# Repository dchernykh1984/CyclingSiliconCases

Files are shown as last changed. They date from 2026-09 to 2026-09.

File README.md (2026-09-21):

# CyclingSiliconCases

Чехлы для велокомпьютеров Garmin. Исходные модели скачаны готовыми, лежат
в [input_data/](input_data/) и правятся кодом поверх них. Готовые STL
собирает CI и прикладывает к релизу — в репозитории их нет.

Python 3.11–3.13, uv, numpy, manifold3d, fontTools. Внешних программ
ставить не нужно: булевы операции считает manifold3d (тот же движок, что
внутри современного OpenSCAD, только как библиотека), картинки рисует свой
растеризатор, шрифт надписи лежит в репозитории.

## Быстрый старт

```bash
make install          # зависимости (uv) и хуки pre-commit
make test             # pytest
make build            # STL в ./dist
make preview          # PNG в ./preview
make inspect          # из каких тел состоят исходники
```

## Что в релизе

| Файл | Прибор | Что сделано |
| --- | --- | --- |
| `garmin-830.stl` | Edge 830 | выпуклая надпись **UBT 8 YEARS** на передней стенке, губы удержания по бокам и спереди |
| `garmin-840.stl` | Edge 840 | только чехол из раскладки, окна под все кнопки, выпуклая надпись **UBT 8 YEARS** на носу |
| `can-lid.stl` | банка для инструмента ⌀77 | выпуклая надпись **UBT 8 YEARS** на наружном торце |
| `bottle-cap.stl` | фляжка для инструмента ⌀72 | выпуклая надпись **UBT 8 YEARS** на наружном торце |
| `can.stl` | — | сама банка, без правок: копия исходника байт в байт |
| `bottle.stl` | — | сама фляжка, без правок формы: повёрнута на дно |

Релиз отдаёт набор целиком: скачали всё, отправили в слайсер, напечатали.
**Все шесть файлов уже лежат так, как их надо печатать** — разворачивать
ничего не нужно.

Банку и фляжку мы не правим. Банка уходит побайтовой копией исходника;
фляжка в исходнике лежала на боку, и её пришлось поставить на дно — это
поворот, а не правка формы: число треугольников и объём до и после
совпадают, и это проверено тестом.

Ориентация у обоих чехлов одна: Z — от спинки к экрану, **+Y — вперёд по
ходу движения** (передняя стенка, там надпись), −Y — к велосипедисту (там
кнопки нижнего торца), −X — левый бок прибора, если смотреть на экран.

### Надпись

Надпись **выпуклая**, высотой 0.8 мм. Под TPU это единственный разумный
вариант: гравировку глубиной в полмиллиметра слайсер на наружной стенке
затирает периметром, а наружу буква растёт свободно. Шрифт — Roboto Black;
при высоте прописной 4 мм стойка буквы выходит 0.92 мм, то есть два
периметра сопла 0.4 мм.

Ни одна стенка чехла не плоская, поэтому надпись кладётся **по поверхности**:
стенка сначала измеряется лучами, потом плитка с буквами гнётся по замеру.
Высота рельефа получается одинаковой по всей строке — 0.78…0.81 мм на 830 и
0.75…0.80 мм на 840, где нос представляет собой скруглённый гребень. Плоская
плитка на том же месте в середине торчала бы на 0.8 мм, а по краям тонула на
два-три миллиметра.

### Кнопки

У Edge 830 три кнопки: питание на левом боку, lap и start/stop на нижнем
торце. Исходный чехол открывает все три — окно 15 × 9 мм слева и окно
44 × 10 мм по всему заднему торцу. Резать нечего, геометрия окон не тронута.

У Edge 840 кнопок семь: питание, вверх и вниз слева, выбор и назад справа,
lap и start/stop на нижнем торце. Точных координат нет ни в мануале, ни в
обзорах — но их знал автор исходника: в полости чехла размечены карманы, где
стенка утончена с 1.75 до 0.75 мм. Слева таких карманов два (50.5…78.0 мм
под пару «вверх/вниз» и 83.5…98.0 мм под питание), справа тоже два
(50.5…65.0 и 83.5…98.0) — три кнопки слева и две справа, ровно как у
прибора. Окна прорезаны **по этим карманам**, так что между ними остаются
рёбра исходника в полную толщину: 6.5 мм до первого окна, 5.5 мм между
окнами слева, 18.5 мм справа и 9 мм до носа.

Кнопки нижнего торца (lap и start/stop) автор не разметил — там была
сплошная стенка 4.5 мм. Их нашли по модели самого прибора: они стоят не
по центру торца, а на завалах углов, в 18.7 мм от середины в обе стороны.
Под них прорезаны **два окна по 7 мм**, между ними остаётся 30 мм торца.

Мембрана 0.75 мм в TPU продавливается пальцем, но полагаться на неё не
стоит: именно тонкая стенка рвётся первой, и цепляются как раз за неё.

### Сверка с прибором

В `input_data` лежит модель самого Edge 840. По ней проверяется то, что
раньше приходилось предполагать:

```bash
uv run cycling-cases fit garmin-840
```

Прибор садится в полость без натяга (зазор по бокам 0.16…0.37 мм),
задняя грань ложится на дно рамки, а вверх его не вынуть: рамка над ним
сужается до 53.4 мм при ширине прибора 58.2 — заводят его снизу, со
стороны крепления. Все семь кнопок попадают в окна с запасом не меньше
0.35 мм по кромке.

Модель приехала под именем «garmin edge 830 Mesh.stl», но по размерам
это Edge 840 — подробности в [input_data/README.md](input_data/README.md).

### Крышки банки и фляжки

Наружный торец у обеих крышек — плоский диск, поэтому надпись ложится
на него без всякого изгиба, и рельеф выходит ровно 0.8 мм по всей
строке. Высота прописной 7 мм, строка 60.7 мм, стойка буквы 1.61 мм.

**Печатать крышку надо надписью вверх, то есть открытой стороной вниз,
и под потолок над резьбой нужна поддержка.** Иначе никак: выпуклые
буквы на грани, которая лежит на столе, пришлось бы печатать в
воздухе. В файле крышка уже стоит так, как её нужно печатать.

Если поддержку ставить не хочется — скажите, и надпись станет
гравировкой: крышка тогда печатается торцом вниз и без поддержек, но
буквы будут вдавленными.

### Посадка

Чехол 830 держался в основном креплением Garmin: загиб, удерживающий прибор
за лицевую рамку, был только на заднем торце. Добавлены такие же губы по
двум бокам и спереди — валик с наклонной нижней гранью (34–45°, печатается
без поддержек), заходящий на рамку на 0.8 мм. По ширине полость 50.6 мм при
приборе 50 мм, так что две губы оставляют натяг 1.0 мм. Над кромкой чехла
губы не поднимаются — это проверено тестом.

Чехол 840 — бампер-рамка: она открыта и сверху, и снизу. Так задумано в
исходнике, и иначе нельзя: снизу к прибору подходит крепление Garmin, сверху
остаётся экран. Держит прибор верхняя губа рамки, она прорезку окон пережила.

## Что где лежит

| Путь | Что там |
| --- | --- |
| `input_data/` | исходные модели, скачанные готовыми; их не пересобрать, это исходный код |
| `src/cycling_cases/recipes.py` | все правки и все числа с объяснением, откуда они взялись |
| `src/cycling_cases/cases.py` | каталог: какой исходник каким рецептом правится |
| `src/cycling_cases/mesh.py` | измерительный инструмент: тела, лучи, сечения, отступы |
| `src/cycling_cases/panel.py` | замер стенки и надпись по измеренной поверхности |
| `src/cycling_cases/lettering.py` | буквы из TTF в плоские контуры |
| `src/cycling_cases/solid.py` | мост к manifold3d и примитивы правок |
| `src/cycling_cases/preview.py` | растеризатор для картинок |
| `tests/` | приёмка исходников и замеры по готовым деталям |

```bash
uv run cycling-cases list                    # что за чехлы и что с ними
uv run cycling-cases inspect Garmin840.stl   # тела, размеры, замкнутость
uv run cycling-cases split Garmin840.stl     # разложить раскладку по телам
uv run cycling-cases build --out dist        # собрать всё
uv run cycling-cases preview --out preview   # отрендерить, чтобы посмотреть
```

## Как добавить ещё один чехол

Чехлы между собой не связаны: общие у них только утилиты — чтение сетки,
замеры, булевы операции и надписи. Добавление нового — четыре шага:

1. положить скачанный STL в `input_data/` и записать в
   [input_data/README.md](input_data/README.md), откуда модель и на каких
   условиях;
2. посмотреть, что в нём: `uv run cycling-cases inspect <файл>`;
3. написать рецепт в `recipes.py` — функция берёт сетку и возвращает тело;
4. дописать одну запись в `CASES` (`src/cycling_cases/cases.py`).

Тест `test_every_source_is_registered` не даст забыть четвёртый шаг.

## Правила, которые не обсуждаются

- **В репозитории только код и исходники.** Собранные STL и превью не
  коммитятся: их делает CI и кладёт в релиз.
- **Геометрия проверяется расчётом, а не на глаз.** Всё, что должно
  поместиться на деталь, считается в `tests/` по готовой детали. Рендер —
  вторая проверка, а не первая.
- **Коммит — одна строка** в стиле conventional commits: от типа зависит
  версия, которую поставит release-please.
- **Чужие формы не переделываем молча.** Откуда взялась модель и на каких
  условиях — в [input_data/README.md](input_data/README.md); что именно мы
  с ней делаем и из каких чисел это следует — в `recipes.py`.

Подробности для тех, кто правит модели, — в `.claude/skills/`.

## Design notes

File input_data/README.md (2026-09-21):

# Исходные модели

Эти файлы нарисовали не мы — они скачаны готовыми. Пересобрать их не из чего,
поэтому они лежат в git наравне с кодом: это исходники, а не артефакты сборки.

| Файл | Что это | Откуда | Лицензия |
| --- | --- | --- | --- |
| `Garmin830.stl` | чехол Garmin Edge 830, одна деталь | **не записано** | **не записано** |
| `Garmin840.stl` | раскладка на стол для Garmin Edge 840: вынос, чехол, два хомута, две проставки | **не записано** | **не записано** |
| `Garmin840Device.stl` | сам велокомпьютер Garmin Edge 840 — шаблон для сверки | прислан заказчиком | **не записано** |
| `obj_1_Lid.stl` | крышка банки для инструмента, ⌀77 мм | прислан заказчиком | **не записано** |
| `obj_2_Can 170mm.stl` | банка для инструмента, ⌀77 × 170 мм | прислан заказчиком | **не записано** |
| `水壶盖3.1无孔.STL` | крышка фляжки для инструмента, ⌀72 мм | прислан заказчиком | **не записано** |
| `水壶3.3.STL` | фляжка для инструмента, ⌀72 × 166 мм | прислан заказчиком | **не записано** |

> **Про банку и фляжку решено: выкладываем как есть.** Владелец
> репозитория не помнит, откуда скачаны эти четыре файла, восстановить
> источник не получилось, и решение — не искать дальше, а публиковать.
> Так что графа «лицензия» у них останется пустой сознательно, а не по
> забывчивости. Риск понятен и принят; если правообладатель однажды
> найдётся, файлы придётся убрать из релизов, а формы нарисовать свои.
>
> На новые модели правило ниже по-прежнему распространяется.

## Почему это важно заполнить

Опыт соседнего проекта: часть моделей на Printables и Thingiverse выложена
под **CC BY-NC** или **CC BY-NC-SA** — некоммерческая лицензия, иногда ещё
и с требованием распространять производное на тех же условиях. Такую модель
нельзя ни положить в публичный репозиторий как основу продукта, ни приложить
к релизу, ни нанести на неё логотип спонсора. Выяснять это лучше до того,
как вокруг чужой формы вырос проект.

Что нужно записать по каждой модели:

- ссылку на страницу, откуда скачано;
- имя автора;
- лицензию дословно (CC0 / CC BY / CC BY-SA / CC BY-NC / CC BY-NC-SA / иное).

Если модель окажется под некоммерческой лицензией, а сделать с ней нужно
что-то, чего лицензия не разрешает, — форму рисуем свою по размерам
велокомпьютера. Размеры — это факты, они не охраняются; охраняется чужое
творческое решение.

## Банка и фляжка под инструмент

Две пары «сосуд + крышка» в форме велосипедной фляжки. Имена файлов
оставлены такими, какими приехали, — в том числе иероглифические и с
пробелом; откуда какой файл, видно по таблице выше.

| Файл | Тел | Габарит, мм | Замкнут |
| --- | --- | --- | --- |
| `obj_1_Lid.stl` | 1 | 76.99 × 76.98 × 16.60 | да |
| `obj_2_Can 170mm.stl` | 1 | 77.00 × 76.99 × 170.00 | да |
| `水壶盖3.1无孔.STL` | 1 | 72.00 × 15.00 × 72.00 | да |
| `水壶3.3.STL` | 1 | 72.00 × 166.17 × 72.00 | да |

У обеих крышек наружный торец — плоский диск, изнутри резьба. Дно
крышки банки 1.60 мм, крышки фляжки 1.75 мм. Крышка фляжки лежит в
файле на боку: её ось идёт вдоль Y, а не Z.

Расширение у иероглифических файлов записано прописными (`.STL`).
Шаблон `*.stl` на Linux их не находит, поэтому в коде расширение
сверяется без учёта регистра.

Правим мы только крышки — на них ложится надпись. Банка и фляжка идут
в релиз без правок формы: смысл релиза в том, чтобы скачать его целиком
и пойти печатать.

Банка уходит **копией байт в байт**, без пересохранения: прогон чужой
сетки через наш экспорт сшил бы вершины и переписал координаты во
float32 — получился бы немного другой файл, выданный за тот же самый.

Фляжка в исходнике лежит на боку (ось вдоль Y), и её мы **ставим на
дно**. Поворот идёт прямо по треугольникам, мимо булева движка: их число
и объём детали до и после совпадают. Дном вниз, а не горлышком — это
тоже проверяется тестом, потому что обратный поворот дал бы и ту же
высоту, и тот же объём.

## Что внутри файлов

Полная опись тел — в скилле `input-models`. Коротко:

- **`Garmin830.stl`** — готовый чехол одним замкнутым телом, 53.6 × 86.6 × 20.1 мм.
  Режется булевыми операциями без предварительной починки.
- **`Garmin840.stl`** — шесть тел на площадке 300 × 169 мм. Сам чехол —
  второе по величине тело, 60.0 × 103.6 × 17.0 мм; у него четыре ребра
  принадлежат четырём граням (деталь сама себя касается), дырок нет.

### Garmin840Device.stl — шаблон самого прибора

Модель прибора, а не чехла: по ней видно, попадают ли окна в кнопки и
лезет ли прибор в полость. Без неё чехол правится вслепую.

**Файл приехал под именем `garmin edge 830 Mesh.stl`, но это не 830.**
Габарит модели 58.29 × 85.53 × 19.66 мм; у Edge 830 — 50 × 82 × 20, у
Edge 840 — 57.8 × 85.1 × 19.6. По ширине разница с 830 почти восемь
миллиметров, в полость чехла 830 (50.6 мм) такой прибор не войдёт. Зато
в полость чехла 840 он садится с зазором 0.2 мм по ширине. Кнопок на
модели семь: три на левом боку, две на правом, две на нижнем торце —
столько их у 840; у 830 их три.

Два обстоятельства, которые надо знать, прежде чем брать этот файл:

* **единицы — десятые доли миллиметра.** В файле габарит 855 × 197 × 583.
  Множитель `0.1` записан в `devices.Device.units`;
* **в репозитории лежит прореженная копия.** Оригинал весит 16 МБ
  (326 456 треугольников) — столько в git класть незачем. В репозиторий
  ушла копия с допуском 0.05 мм: 17 874 треугольника, 0.9 МБ, габарит
  отличается на 0.025 мм. Замеры кнопок по ней совпадают с замерами по
  оригиналу до сотых.

Оригиналы сырых сканов кладите в `input_data` под именем с `Mesh` —
git такие файлы игнорирует. Прореженная копия делается так:

```python
from cycling_cases import solid
from cycling_cases.mesh import parts, read_stl, write_stl
body = parts(read_stl(Path("input_data/имя Mesh.stl")))[0].triangles
write_stl(Path("input_data/Имя.stl"), solid.to_triangles(solid.from_triangles(body).simplify(0.5)))
```

(`simplify` меряет допуск в единицах файла, поэтому 0.5 — это 0.05 мм.)

### Разметка кнопок в чехле 840

Автор исходника знал, где у Edge 840 боковые кнопки, и оставил под ними
карманы: стенка там утончена с 1.75 до 0.75 мм. Сквозное окно он прорезал
только одно на бок — 9 × 9 мм в 4…13 мм от заднего торца.

| Бок | Карманы по длине (Y исходника) | Длина |
| --- | --- | --- |
| левый | 50.5…78.0 и 83.5…98.0 | 27.5 и 14.5 мм |
| правый | 50.5…65.0 и 83.5…98.0 | 14.5 и 14.5 мм |

Три зоны слева и две справа — ровно столько боковых кнопок у Edge 840
(питание, вверх, вниз слева; выбор и назад справа). Карманы кончаются сверху
на той же высоте 6.7 мм, что и штатное окно, — это и есть пояс кнопок.

Наши окна режутся ровно по этой разметке, поэтому она проверяется приёмкой
(`test_the_840_case_has_its_buttons_marked_from_the_inside`): если исходник
заменят, а карманы окажутся в других местах, тест скажет об этом до того, как
окна уедут мимо кнопок.

Модель прибора эту разметку подтвердила: все пять боковых кнопок садятся в
свои карманы, причём верхняя кромка каждой кнопки совпадает с кромкой
кармана с точностью 0.01 мм. А вот кнопки нижнего торца автор не разметил
никак — их пришлось искать по модели прибора, и они оказались не по центру
торца, а на завалах углов, в 18.7 мм от середины.

Посмотреть самому:

```bash
uv run cycling-cases inspect Garmin840.stl
uv run cycling-cases split Garmin840.stl --out dist/parts
```

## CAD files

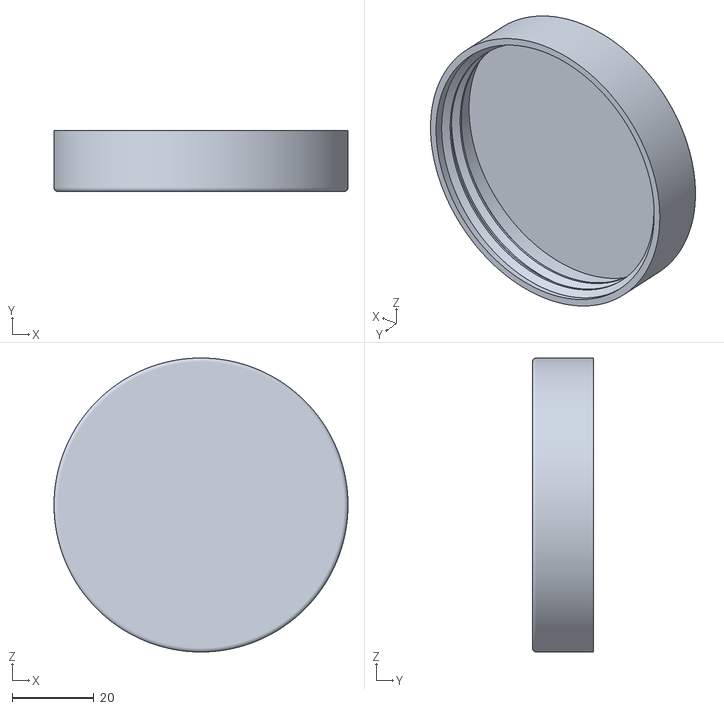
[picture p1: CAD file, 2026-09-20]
input_data/水壶盖3.1无孔.STL
72.0 x 15.0 x 72.0

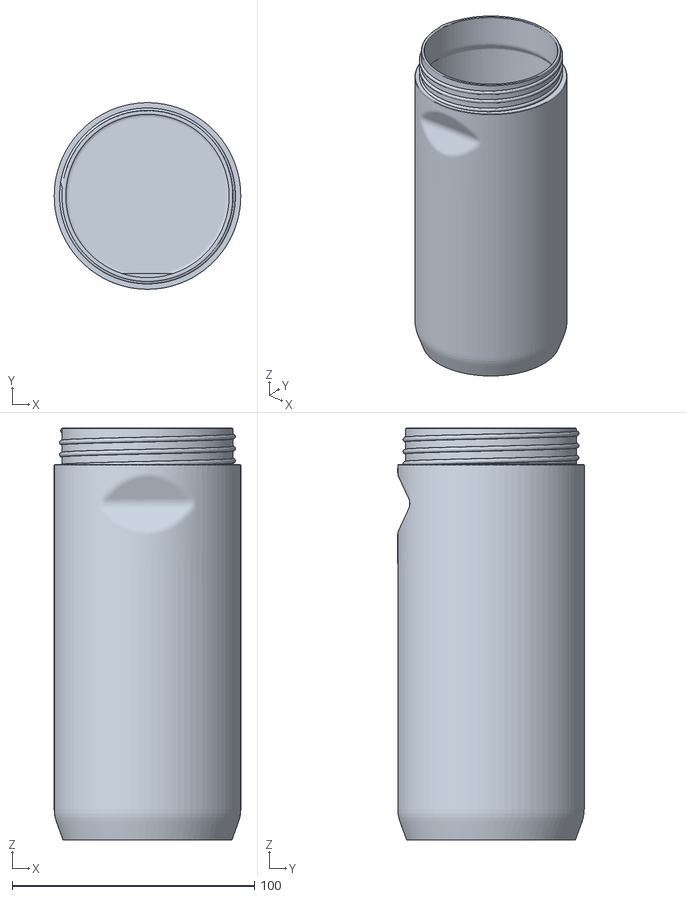
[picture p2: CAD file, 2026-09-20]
input_data/obj_2_Can 170mm.stl
77.0 x 77.0 x 170.0

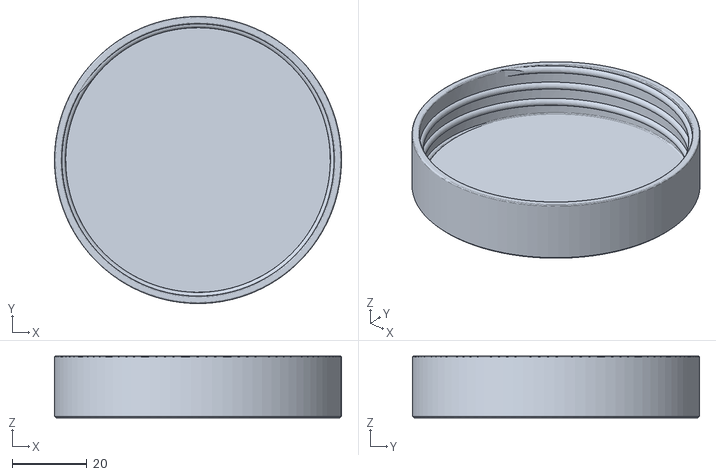
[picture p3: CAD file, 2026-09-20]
input_data/obj_1_Lid.stl
77.0 x 77.0 x 16.6

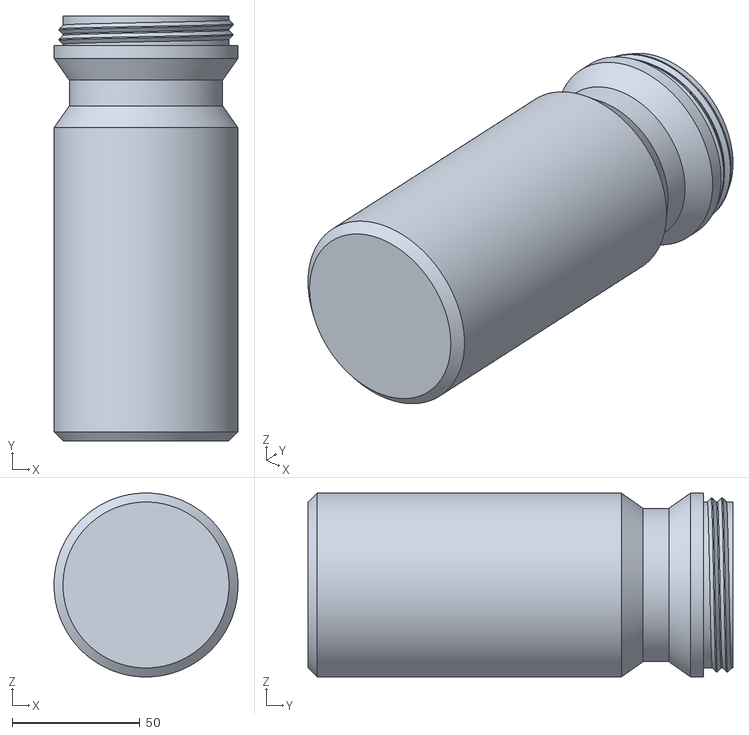
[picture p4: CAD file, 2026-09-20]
input_data/水壶3.3.STL
72.0 x 166.2 x 72.0

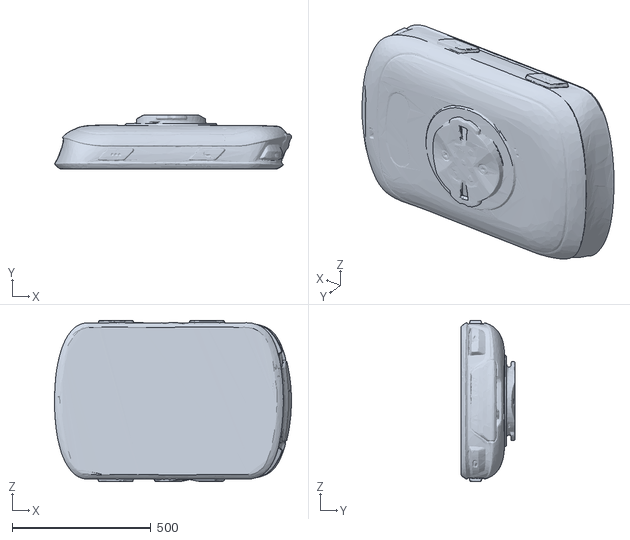
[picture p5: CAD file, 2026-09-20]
input_data/Garmin840Device.stl
855.3 x 196.6 x 582.7

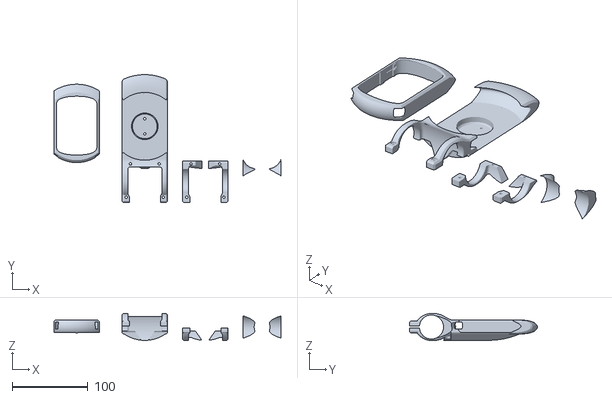
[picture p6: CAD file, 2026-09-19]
input_data/Garmin840.stl
300.0 x 168.9 x 35.8

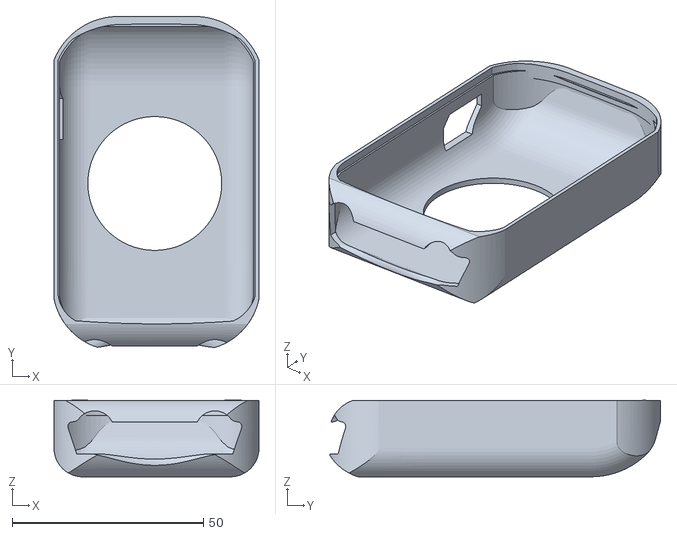
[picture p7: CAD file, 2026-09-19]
input_data/Garmin830.stl
53.6 x 86.6 x 20.1

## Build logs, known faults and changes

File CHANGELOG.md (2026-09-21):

# Changelog

## [0.6.0](https://github.com/dchernykh1984/CyclingSiliconCases/compare/v0.5.0...v0.6.0) (2026-09-21)

### Новое

* stand the bottle on its base for the release ([1a5e3a0](https://github.com/dchernykh1984/CyclingSiliconCases/commit/1a5e3a0651d34a606a679f7f857b3dc314d89a54))

### Исправления

* refuse to ship a vessel that would arrive lying on its side ([2d7fbbd](https://github.com/dchernykh1984/CyclingSiliconCases/commit/2d7fbbdce4d150dd63d69f4138aad10c27a39607))

## [0.5.0](https://github.com/dchernykh1984/CyclingSiliconCases/compare/v0.4.0...v0.5.0) (2026-09-21)

### Новое

* ship the can and the bottle in the release next to their lids ([fab8809](https://github.com/dchernykh1984/CyclingSiliconCases/commit/fab8809c51b2300604a99b1dbe5cafdf8d7ac3d0))

### Исправления

* name every part when the slug is wrong and warn that the bottle lies down ([ee3ee9b](https://github.com/dchernykh1984/CyclingSiliconCases/commit/ee3ee9bc9438f732b79d5dab3e8857595bd3147c))

## [0.4.0](https://github.com/dchernykh1984/CyclingSiliconCases/compare/v0.3.0...v0.4.0) (2026-09-20)

### Новое

* emboss UBT 8 YEARS on the lids of both tool bottles ([fbb9875](https://github.com/dchernykh1984/CyclingSiliconCases/commit/fbb987507b6574b14130ce6c07f36b2ae14362e2))

### Документация

* correct the measured radii in the lid recipe ([9eefc05](https://github.com/dchernykh1984/CyclingSiliconCases/commit/9eefc05a36bec25f00aee1e824ad01734f041524))
* describe the tool bottles and how their lids print ([68f975c](https://github.com/dchernykh1984/CyclingSiliconCases/commit/68f975c725c9d9767d421a9da2119568c3d6785d))
* forbid tool attribution everywhere, not only in commits ([25d795d](https://github.com/dchernykh1984/CyclingSiliconCases/commit/25d795d390cae906171ae6652c0e9d8a0229354a))

## [0.3.0](https://github.com/dchernykh1984/CyclingSiliconCases/compare/v0.2.0...v0.3.0) (2026-09-20)

### Новое

* find the buttons of the device from its own model ([ed3c8e3](https://github.com/dchernykh1984/CyclingSiliconCases/commit/ed3c8e347a55971b18483202f2df6fdbb68bad99))
* report how the device sits in its case ([5edcac4](https://github.com/dchernykh1984/CyclingSiliconCases/commit/5edcac407079ddda2d8b62748b819c5c86ee60ed))

### Исправления

* cut the rear windows where the bottom buttons actually are ([6e4e00c](https://github.com/dchernykh1984/CyclingSiliconCases/commit/6e4e00c2485762f377bb569dea015bfef35866c6))

### Документация

* write down the device template and what it proved ([0197b7b](https://github.com/dchernykh1984/CyclingSiliconCases/commit/0197b7ba08e538beddd6fb28ac5b3d4823e14821))

## [0.2.0](https://github.com/dchernykh1984/CyclingSiliconCases/compare/v0.1.0...v0.2.0) (2026-09-19)

### Новое

* emboss UBT 8 YEARS and open every button window on both cases ([0757bbe](https://github.com/dchernykh1984/CyclingSiliconCases/commit/0757bbeec483d9ee4c88882a80f2b430e1e509da))
* measure wall thickness and openings with rays ([a5eb3bd](https://github.com/dchernykh1984/CyclingSiliconCases/commit/a5eb3bd900fcb40b4608e6eb781cc52dc3f5390d))

### Исправления

* bound ray casting memory and answer a miss when nothing can be hit ([192405e](https://github.com/dchernykh1984/CyclingSiliconCases/commit/192405e9363cf056697801dfbb1c8ee4f7eacd7a))
* fail loudly instead of quietly shipping an empty case ([f4ed82a](https://github.com/dchernykh1984/CyclingSiliconCases/commit/f4ed82af57c219c87994e3869a1327c987edd5db))

### Документация

* describe the manifold3d toolchain and the button pockets of the 840 ([7188298](https://github.com/dchernykh1984/CyclingSiliconCases/commit/718829803e059f1831098e11bf8bed5a7396bcfc))

## 0.1.0 (2026-09-19)

### Новое

* build printable cases from the source models ([50a97d9](https://github.com/dchernykh1984/CyclingSiliconCases/commit/50a97d900548456858fc8d0cf0f9a95e2c4951ff))

### Документация

* describe the sources and how the project is built ([95ef949](https://github.com/dchernykh1984/CyclingSiliconCases/commit/95ef949f725c63f4fdb9bcc674f2a395ca04442a))

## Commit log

2026-09-19 garmin 830 and 840 input data
    [Garmin830.stl, Garmin840.stl]
2026-09-19 feat: build printable cases from the source models
2026-09-19 feat: emboss UBT 8 YEARS and open every button window on both cases
2026-09-19 docs: describe the manifold3d toolchain and the button pockets of the 840
2026-09-19 fix: fail loudly instead of quietly shipping an empty case
2026-09-20 feat: find the buttons of the device from its own model
    [Garmin840Device.stl]
2026-09-20 fix: cut the rear windows where the bottom buttons actually are
2026-09-20 feat: report how the device sits in its case
2026-09-20 docs: write down the device template and what it proved
2026-09-20 feat: emboss UBT 8 YEARS on the lids of both tool bottles
    [obj_1_Lid.stl, obj_2_Can 170mm.stl, 水壶3.3.STL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]
2026-09-20 docs: describe the tool bottles and how their lids print
